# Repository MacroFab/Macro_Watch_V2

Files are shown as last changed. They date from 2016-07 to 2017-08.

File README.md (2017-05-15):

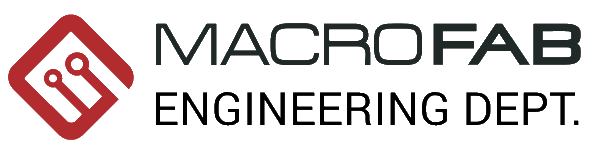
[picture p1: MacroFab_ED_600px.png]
MF_ED_Logo

***
### Macro_Watch_V2
***
**Low cost, binary watch based off the Silicon Labs EFM8SB10F2G-A-QFN20R MCU for promotional purposes at MacroFab, INC.**

This repository contains all the documentation and instructions needed to build a Macro_Watch. The Macro_Watch is designed to be mounted on an ESD wrist band. It is designed to be programmed with the [Silicon Labs USB Debug Adapter](http://www.silabs.com/products/mcu/Pages/USBDebug.aspx) and the [SiLabs2TC](https://github.com/MacroFab/Macro_Articles/tree/master/SiLabs2TC) board. 

Check the [MacroFab, INC. Engineering Blog](https://macrofab.com/blog/engineering/) for more information.

***
**License Information**

This project is under the [Creative Commons Attribution-ShareAlike 4.0 International License](LICENSE.md). This project is provided with no warranty and should be used at your own risk. 

***
**Board Layout**

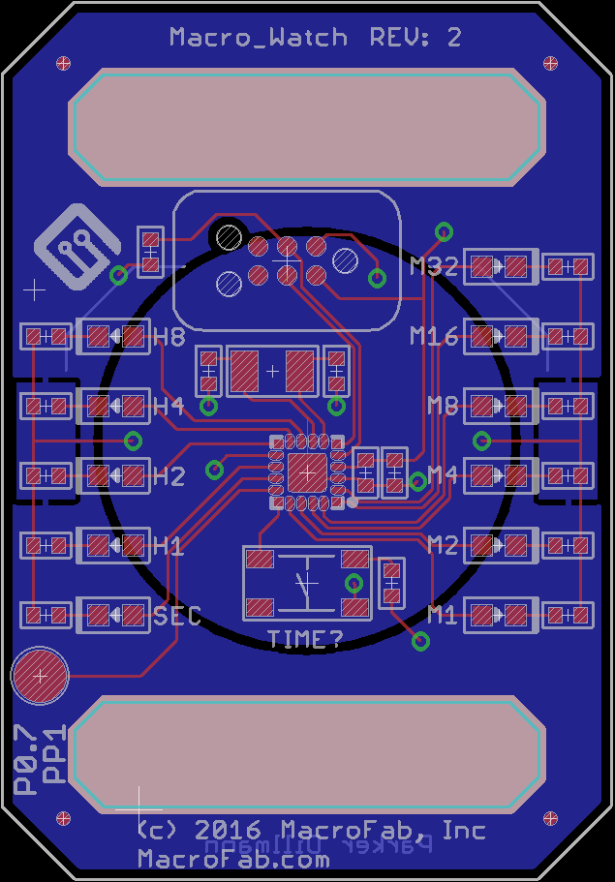
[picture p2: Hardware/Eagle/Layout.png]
Macro_Watch_V2_Layout


***
**Board Schematic**

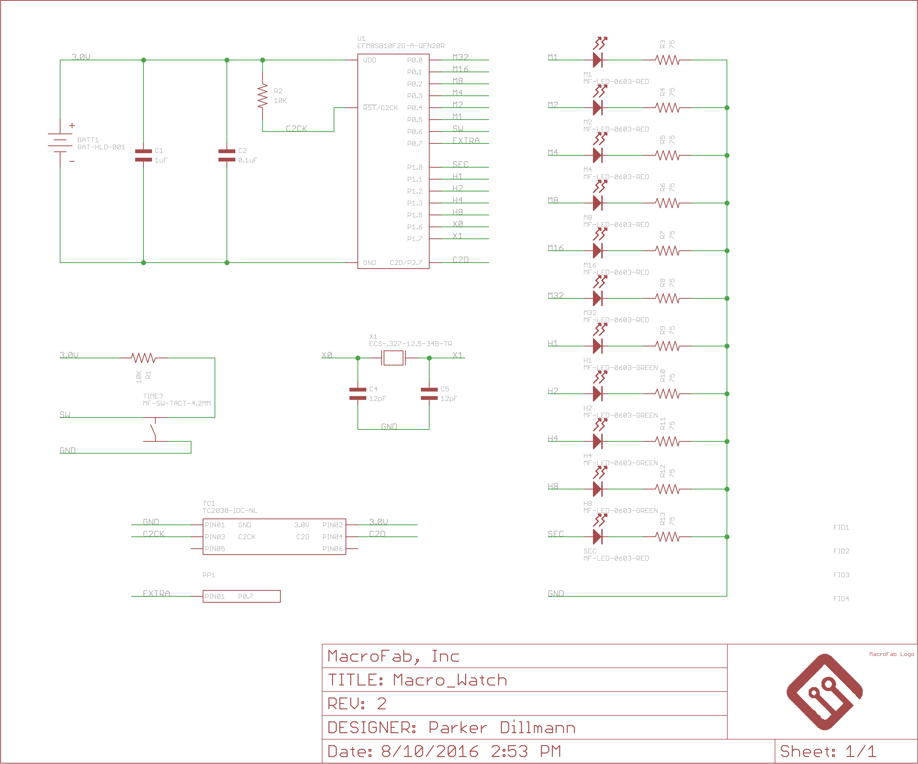
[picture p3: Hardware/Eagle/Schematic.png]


***
**Completed Macro_Watch V2**

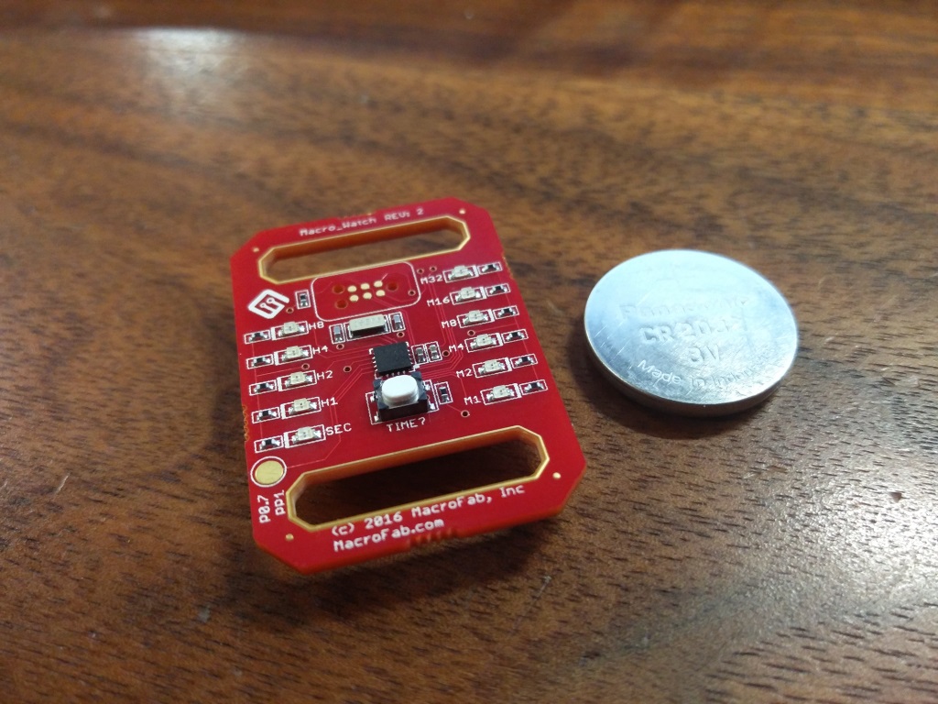
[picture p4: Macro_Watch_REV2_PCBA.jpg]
Completed_Macro_Watch_V2


***
**Macro_Watch V2 being programmed**

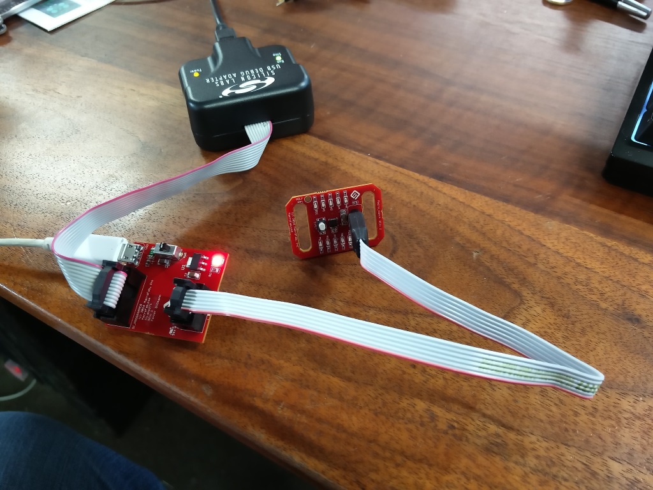
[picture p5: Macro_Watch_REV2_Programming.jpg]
Macro_Watch_V2_programming


***
**Directory listing of the repository**

| Directory | Description |
|---|---|
| Hardware | Contains all the hardware files for the Macro_Watch. Designed with Eagle V6.0+. | 
| Software | Has all the firmware that needs to be loaded onto the Macro_Watch. Written in C for Simplicity Studio. |

***
**Credits**

Designed by:   
Parker Dillmann  

Software by:   
Parker Dillmann  

***

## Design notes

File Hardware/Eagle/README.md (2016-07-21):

###Macro_Watch Hardware
***
**Low cost, binary watch based off the Silicon Labs EFM8SB10F2G-A-QFN20R MCU for promotional purposes at MacroFab, INC.**

***
Layout Image

***
Schematic Image

***
Gerber Top Drawing

Files are for Eagle V6.0+. Gerber files can be found in the camfiles directory. See main directory for licensing.

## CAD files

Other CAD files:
Software/Macro_Watch_V2/Keil 8051 v9.53 - Debug/src/main.OBJ
Software/Macro_Watch_V2/Keil 8051 v9.53 - Debug/src/InitDevice.OBJ
Software/Macro_Watch_V2/Keil 8051 v9.53 - Debug/src/SILABS_STARTUP.OBJ

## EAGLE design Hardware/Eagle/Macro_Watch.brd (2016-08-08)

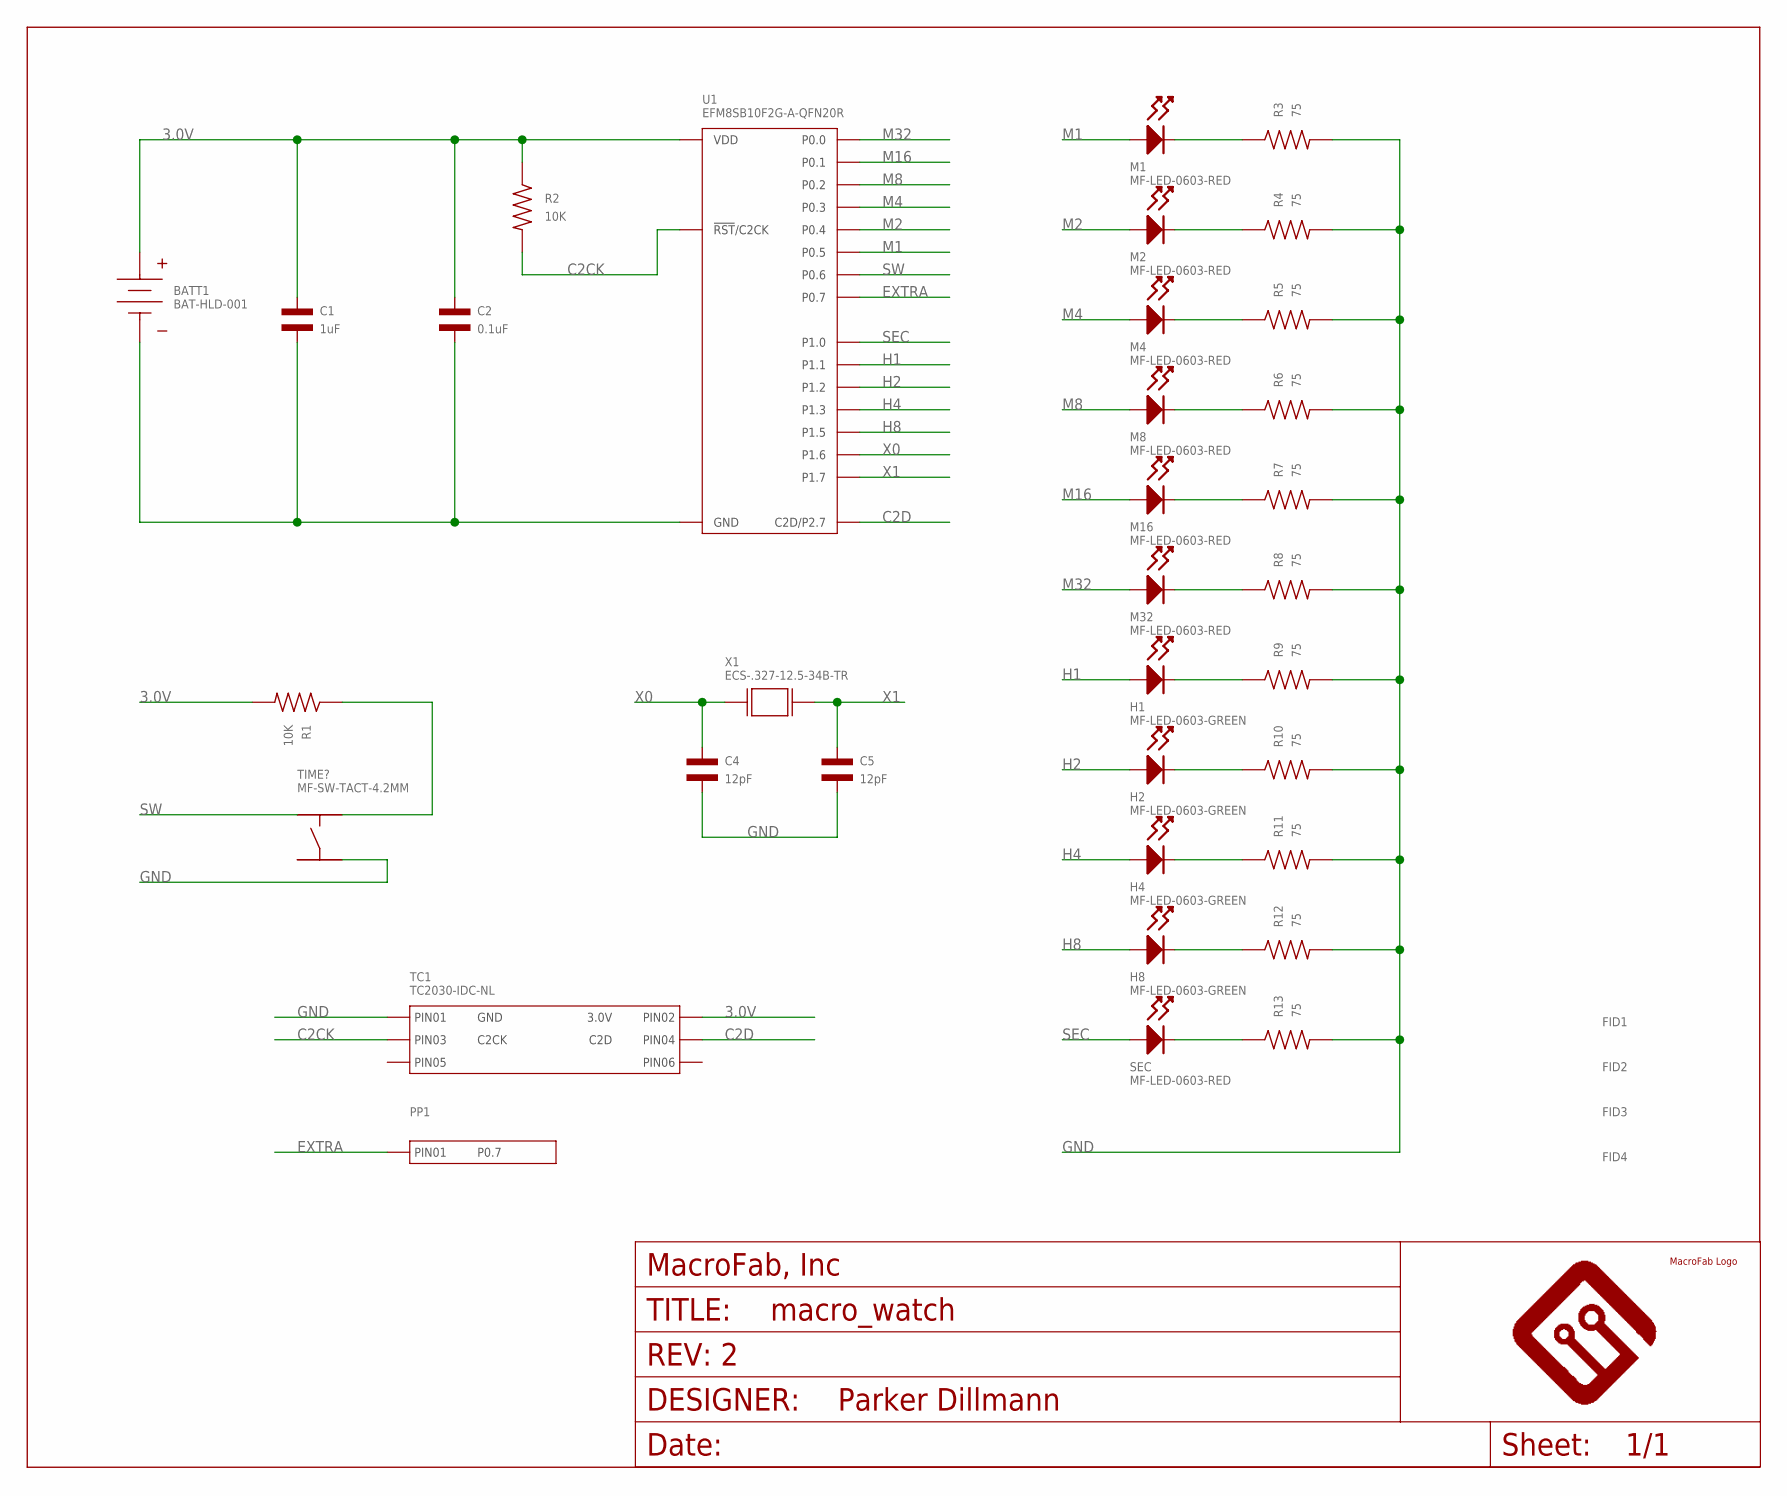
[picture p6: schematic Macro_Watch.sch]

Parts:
BATT1: BAT-HLD-001
C1: 1uF; C0402; MPN MF-CAP-0402-1uF
C2: 0.1uF; C0402; MPN MF-CAP-0402-0.1uF
C4, C5: 12pF; C0402; MPN 500R07S120KV4T
FID1, FID2, FID3, FID4: FIDUCIAL_0.5MM
FRAME1: MF_FRAMEDEFAULT; MF_FRAME_DEFAULT
H1, H2, H4, H8: MF-LED-0603-GREEN; LED0603
M1, M2, M4, M8, M16, M32: MF-LED-0603-RED; LED0603
PP1: POGO_PIN_01X01_70-9150; POGO_PIN_70-9150
R1, R2: 10K; R0402; MPN MF-RES-0402-10K
R3, R4, R5, R6, R7, R8, R9, R10, R11, R12, R13: 75; R0402; MPN MF-RES-0402-75
SEC: MF-LED-0603-RED; LED0603
TC1: TC2030-IDC-NL
TIME?: MF-SW-TACT-4.2MM; TACT4.2MM
U1: EFM8SB10F2G-A-QFN20R; EFM8SB10F(2/4/8)G-A-QFN20; MPN EFM8SB10F2G-A-QFN20R
U$1: MF_LOGOLOGO_SMALL; MF_LOGO_SMALL
X1: ECS-.327-12.5-34B-TR; ECX-31B_SERIES; MPN ECS-.327-12.5-34B-TR

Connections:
3.0V: BATT1.POS_0 (POS), BATT1.POS_1 (POS), C1.P$1, C2.P$1, R1.P$2, R2.P$1, TC1.P$2 (PIN2), U1.P$4 (VDD)
C2CK: R2.P$2, TC1.P$3 (PIN3), U1.P$5 (!RST!/C2CK)
C2D: TC1.P$4 (PIN4), U1.P$6 (C2D/P2.7)
EXTRA: PP1.P$1, U1.P$15 (P0.7)
GND: BATT1.NEG_0 (NEG), C1.P$2, C2.P$2, C4.P$2, C5.P$2, R3.P$2, R4.P$2, R5.P$2, R6.P$2, R7.P$2, R8.P$2, R9.P$2, R10.P$2, R11.P$2, R12.P$2, R13.P$2, TC1.P$1 (PIN1), TIME?.P$4, U1.P$3 (GND), U1.P$12 (GND), U1.PAD (GND)
H1: H1.ANODE, U1.P$13 (P1.1)
H2: H2.ANODE, U1.P$11 (P1.2)
H4: H4.ANODE, U1.P$10 (P1.3)
H8: H8.ANODE, U1.P$9 (P1.5)
M1: M1.ANODE, U1.P$17 (P0.5)
M2: M2.ANODE, U1.P$18 (P0.4)
M4: M4.ANODE, U1.P$19 (P0.3)
M8: M8.ANODE, U1.P$20 (P0.2)
M16: M16.ANODE, U1.P$1 (P0.1)
M32: M32.ANODE, U1.P$2 (P0.0)
unnamed: R1.P$1, TIME?.P$2
unnamed: M1.CATHODE, R3.P$1
unnamed: M2.CATHODE, R4.P$1
unnamed: M4.CATHODE, R5.P$1
unnamed: M8.CATHODE, R6.P$1
unnamed: M16.CATHODE, R7.P$1
unnamed: M32.CATHODE, R8.P$1
unnamed: H1.CATHODE, R9.P$1
unnamed: H2.CATHODE, R10.P$1
unnamed: H4.CATHODE, R11.P$1
unnamed: H8.CATHODE, R12.P$1
unnamed: R13.P$1, SEC.CATHODE
SEC: SEC.ANODE, U1.P$14 (P1.0)
SW: TIME?.P$1, U1.P$16 (P0.6)
X0: C4.P$1, U1.P$8 (P1.6), X1.P$1 (X0)
X1: C5.P$1, U1.P$7 (P1.7), X1.P$2 (X1)

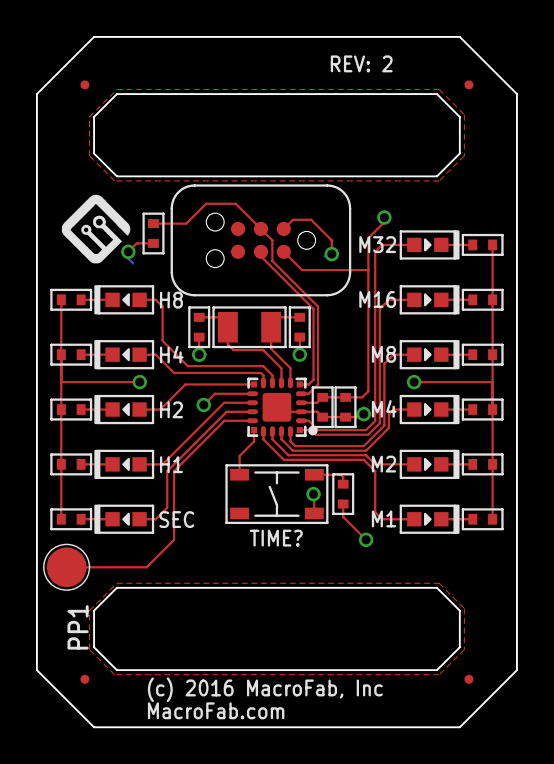
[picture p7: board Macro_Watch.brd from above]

Board: 2 copper layers, 26.7 x 38.4 mm, 40 parts (1 on the bottom side), 31 nets.

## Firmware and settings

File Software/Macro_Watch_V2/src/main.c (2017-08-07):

#include <si_toolchain.h>
#include <SI_EFM8SB1_Register_Enums.h>
#include "InitDevice.h"

SI_SBIT(M32, SFR_P0, 0);
SI_SBIT(M16, SFR_P0, 1);
SI_SBIT(M8, SFR_P0, 2);
SI_SBIT(M4, SFR_P0, 3);
SI_SBIT(M2, SFR_P0, 4);
SI_SBIT(M1, SFR_P0, 5);

SI_SBIT(EXTRA, SFR_P0, 7);

SI_SBIT(SEC, SFR_P1, 0);
SI_SBIT(H1, SFR_P1, 1);
SI_SBIT(H2, SFR_P1, 2);
SI_SBIT(H4, SFR_P1, 3);
SI_SBIT(H8, SFR_P1, 5);

SI_SBIT(SW, SFR_P0, 6);

#define SUSPEND            		    0x40        // Value to write to PMU0CF to place
                                                // the device in Suspend mode

#define SLEEP              		    0x80        // Value to write to PMU0CF to place
                                                // the device in Sleep Mode

#define POWER_MODE     			    SLEEP       // Select between Suspend and Sleep
                                                // mode. When debugging, if the
                                                // MCU is stopped/halted while
                                                // in Sleep Mode, the connection
                                                // to the IDE will be lost. The
                                                // IDE connection will not be lost
                                                // if the MCU is stopped/halted
                                                // while in suspend mode.

SI_SEGMENT_VARIABLE(wakeup_source, uint8_t, SI_SEG_XDATA);

int STATE = 0;

int BUTT_action = 0;

int Disp_timeout = 0;
int Change_time = 0;
int ADVCLKDELAY = 0;
int ADVCLKCNT = 0;

int SECONDS = 0;
int MINUTES = 12;
int HOUR = 12;

void delay_ms(int);
void TEST_LED_PATTERN(void);


int main(void)
{
	enter_DefaultMode_from_RESET();

    TEST_LED_PATTERN();

	M32 = 0;
	M16 = 0;
	M8 = 0;
	M4 = 0;
	M2 = 0;
	M1 = 0;
	SEC = 0;
	H1 = 0;
	H2 = 0;
	H4 = 0;
	H8 = 0;
	EXTRA = 0;

    // Set P0.6 to Digital Input for port match detection.
    P0MASK |= P0MASK_B6__COMPARED;
    P0MDIN |= P0MDIN_B6__DIGITAL;

	while (1)
	{
		//PMU0CF = 0x20;
		//RSTSRC = 0x04;                // Disable VDDMON, leave missing clock
									  // detector enabled
		// Put device to sleep
		PMU0CF = 0x0E | POWER_MODE;   // To change between SUSPEND or SLEEP
									  // modes, change the POWER_MODE
									  // definition in the global constants

		while (!(VDM0CN & 0x20));     // Wait for VDDOK to be set to 1

		EXTRA = 1;

        // Read the wake-up source flags
        wakeup_source = PMU0CF & 0x1F;

        // Clear the wake-up source flags
        //PMU0CF = 0x20;
        PMU0CF |= PMU0CF_CLEAR__ALL_FLAGS;

        // Check for smaRTClock alarm
        if (wakeup_source & 0x04)
        {
        	SECONDS++;
        	if(SECONDS == 60)
        	{
        		SECONDS = 0;
        		MINUTES++;
        		if(MINUTES == 60)
        		{
        			MINUTES = 0;
        			HOUR++;
        			if(HOUR == 13)
        			{
        				HOUR = 1;
        			}
        		}
        	}
        }

        switch(STATE)
        {
        case 0 : //OFF STATE

        	M32 = 0;
        	M16 = 0;
        	M8 = 0;
        	M4 = 0;
        	M2 = 0;
        	M1 = 0;
        	SEC = 0;
        	H1 = 0;
        	H2 = 0;
        	H4 = 0;
        	H8 = 0;

        	// Check for Port Match event
        	if (wakeup_source & 0x02)
        	{
        		STATE = 1;
        		BUTT_action = 1;

        		H1 = HOUR & 0x01;
				H2 = (HOUR >> 1) & 0x01;
				H4 = (HOUR >> 2) & 0x01;
				H8 = (HOUR >> 3) & 0x01;

				M1  = MINUTES & 0x01;
				M2  = (MINUTES >> 1) & 0x01;
				M4  = (MINUTES >> 2) & 0x01;
				M8  = (MINUTES >> 3) & 0x01;
				M16  = (MINUTES >> 4) & 0x01;
				M32  = (MINUTES >> 5) & 0x01;

				SEC = !SEC;
        	}
        	else
        	{
        		STATE = 0;
        		BUTT_action = 0;
        	}
        	break;
        case 1 : //BUTTON PRESSED. RECORD TIME.

        	H1 = HOUR & 0x01;
			H2 = (HOUR >> 1) & 0x01;
			H4 = (HOUR >> 2) & 0x01;
			H8 = (HOUR >> 3) & 0x01;

			M1  = MINUTES & 0x01;
			M2  = (MINUTES >> 1) & 0x01;
			M4  = (MINUTES >> 2) & 0x01;
			M8  = (MINUTES >> 3) & 0x01;
			M16  = (MINUTES >> 4) & 0x01;
			M32  = (MINUTES >> 5) & 0x01;

			SEC = !SEC;

        	Disp_timeout = SECONDS + 10;

        	if(Disp_timeout >= 60)
			{
				Disp_timeout = Disp_timeout - 60;
			}

			Change_time = SECONDS;
			Change_time = Change_time + 3;

			if(Change_time >= 60)
			{
				Change_time = Change_time - 60;
			}

			STATE = 2;

			break;
        case 2 : //TURN ON DISPLAY. AND WAIT FOR TIMEOUTS

        	H1 = HOUR & 0x01;
			H2 = (HOUR >> 1) & 0x01;
			H4 = (HOUR >> 2) & 0x01;
			H8 = (HOUR >> 3) & 0x01;

			M1  = MINUTES & 0x01;
			M2  = (MINUTES >> 1) & 0x01;
			M4  = (MINUTES >> 2) & 0x01;
			M8  = (MINUTES >> 3) & 0x01;
			M16  = (MINUTES >> 4) & 0x01;
			M32  = (MINUTES >> 5) & 0x01;

			SEC = !SEC;

			//Display time out. Time to turn off display.
			if(Disp_timeout == SECONDS)
			{
				STATE = 0;
				BUTT_action = BUTT_action;
			}

			//Button is pressed again. Reset display time and set button action flag.
			else if(SW == 0 && BUTT_action == 0)
			{
				STATE = 1;
				BUTT_action = 1;
			}

			//Button is held for 3 seconds. Time to hack time!
			else if(Change_time == SECONDS && SW == 0 && BUTT_action == 1)
			{
				STATE = 3;
				BUTT_action = BUTT_action;
				ADVCLKDELAY = 50;
				ADVCLKCNT   = 2;
			}
			//Button has stopped being pressed. Clear button action flag.
			else if(SW == 1 && BUTT_action == 1)
			{
				STATE = 2;
				BUTT_action = 0;
			}

			break;

        case 3 : //INCREASE TIME AND DISPLAY TIME.
        	//Switch held. Increase time.
			while(SW == 0)
			{
				SECONDS = 0;
				MINUTES = MINUTES + 1;
				if(MINUTES == 60)
				{
					MINUTES = 0;
					HOUR = HOUR + 1;
					if(HOUR == 13)
					{
						HOUR = 1;
					}
				}
				//Calculate "acceleration" of time hacking.
				ADVCLKCNT = ADVCLKCNT - 1;
				if(ADVCLKCNT == 0 && ADVCLKDELAY > 5)
				{
					ADVCLKCNT = 3;
					ADVCLKDELAY = ADVCLKDELAY - 5;
				}

				H1 = HOUR & 0x01;
				H2 = (HOUR >> 1) & 0x01;
				H4 = (HOUR >> 2) & 0x01;
				H8 = (HOUR >> 3) & 0x01;

				M1  = MINUTES & 0x01;
				M2  = (MINUTES >> 1) & 0x01;
				M4  = (MINUTES >> 2) & 0x01;
				M8  = (MINUTES >> 3) & 0x01;
				M16  = (MINUTES >> 4) & 0x01;
				M32  = (MINUTES >> 5) & 0x01;

				SEC = 0;

				delay_ms(ADVCLKDELAY);


			}
			//Switch released. Recalculate on time.
			if(SW == 1)
			{
				STATE = 1;
			}

			break;


		//Never supposed to get here but just encase of cosmic radiation flipping a bit.
		default:

			STATE = 0;

			break;
        }

        EXTRA = 0;
	}
}

void delay_ms(int milliseconds)
{
	milliseconds = milliseconds * 32;
	while((milliseconds) > 0)
	{
		milliseconds--;
	}
}

void TEST_LED_PATTERN(void)
{
	M32 = 1;
	delay_ms(20);
	M32 = 0;

	M16 = 1;
	delay_ms(20);
	M16 = 0;

	M8 = 1;
	delay_ms(20);
	M8 = 0;

	M4 = 1;
	delay_ms(20);
	M4 = 0;

	M2 = 1;
	delay_ms(20);
	M2 = 0;

	M1 = 1;
	delay_ms(20);
	M1 = 0;

	SEC = 1;
	delay_ms(20);
	SEC = 0;

	H1 = 1;
	delay_ms(20);
	H1 = 0;

	H2 = 1;
	delay_ms(20);
	H2 = 0;

	H4 = 1;
	delay_ms(20);
	H4 = 0;

	H8 = 1;
	delay_ms(20);
	H8 = 0;
}

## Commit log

2016-06-27 First push of VS of MacroWatch.
    [Macro_Watch.GBL, Macro_Watch.GBO, Macro_Watch.GBP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]
2016-07-21 Code and hardware updated for first production run.
    [InitDevice.OBJ, Macro_Watch_V2_main.OBJ, SILABS_STARTUP.OBJ]
2016-08-08 Updated files to latest Library.
    [Macro_Watch.brd, Macro_Watch.sch]
2016-08-10 Adding documentation.
    [Macro_Watch.sch]
2017-08-07 Fixed software bug in SiLabs HWConfig
    [InitDevice.OBJ, Macro_Watch_V2_main.OBJ, SILABS_STARTUP.OBJ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]

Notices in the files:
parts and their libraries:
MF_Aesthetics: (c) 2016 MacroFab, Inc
